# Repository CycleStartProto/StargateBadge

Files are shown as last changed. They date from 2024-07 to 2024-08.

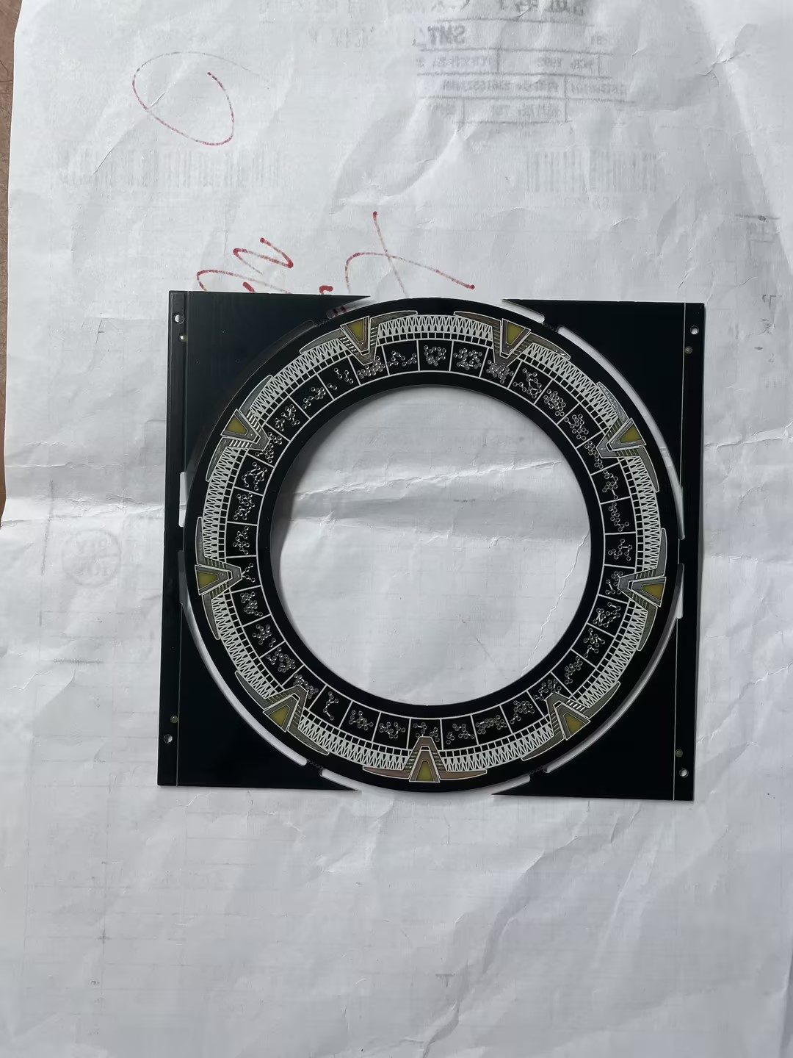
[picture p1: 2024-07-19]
pictures/1.jpg

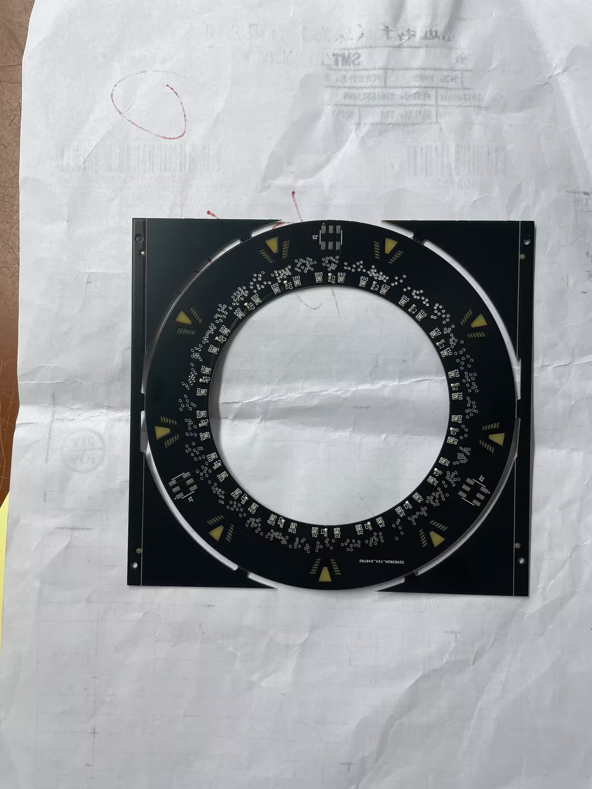
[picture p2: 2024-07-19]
pictures/2.jpg

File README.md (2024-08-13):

# StargateBadge
A fun little limited run badge project


Full repo with 3d files: https://drive.google.com/file/d/1T7bEAc4z4qsCiE_2lE-3noR91gCBkVOr/view?usp=drive_link

# Known Issues
- 3d print gets really close to LEDs and can damage them during assembly, be VERY CAREFUL
  - Doing a light debur with a knife on the edges of the 3d print helps aleviate this issue
- Once a single LED is damaged it can cause large sections of the gate to stop working
  - Only fix is to rework the damaged LED.

# Mechanical Details
- Main structure is provided by the 3d printed core and the 2 circuit boards sandwitched together. 
- 3 pieces of 2x3 pin header hold the whole stack together through friction
- The infinity mirror is made from a 2.5mm thich fully silvered mirror, a piece of 2mm acrylic, and a 1mm 40% semi silvered mirror
- The infinity mirror stack is held in place with another 3d printed spacer to keep it in place and together

# Electrical Details
- 2000mAh Lipo Battery with TP4056 charge controller (set for 600mA charge rate) and power sharing circuit.
- Battery voltage measurement through 750k resistor (to prevent phantom-drain when powerd off) and op-amp buffer to microcontroller ADC
- MT3608 5V Boost converter circuit to ensure consistent LED Supply Voltage
- RP2040 Microcontroller with 128Mbit flash chip
- LIS3DHTR Accelerometer
- 74LVC4245APW Level shifter to ensure reliable addressable LED operation
- a total of 126 XL-1010RGBC-WS2812B 1mmx1mm addressable LEDs

# Firmware Details
- Adafruit Circuitpython and accompanying libraries for accelerometer and addressable LED's
- Custom animation parser for reading animations stored in plain-text format on flash (see command structure.txt in firmware folder for more info)
- Main settings stored as .txt file on flash (see BoardSettings.txt)
- Seperate USB-Serial endpoint exposed to accept animation commands
  - Same command structure as animation file
  - Will execute along side or on top of commanded animation file
  - Can be used to stream animations from seperate pc/controller
- 4 tactile buttons
  - UK1 (GP10) Dial outgoing wormhole
  - UK2 (GP11) Display battery voltage (will interrupt dial animations)
  - UK3 (GP12) Mode Select (switches between dial mode, accelerometer display mode, and rainbow mode)
  - UK4 (GP13) Incoming wormhole
- In random dial mode (default mode) gate will randomly dial an incoming or outgoing sequence based on randomization settings in BoardSettings.txt

# Animation Generators
- run on PC to quickly generate animation files to be loaded onto board
- Animation generators require python 3.9 or newer installed
- Run GenerateDialSeq.py to generate incoming, outgoing, idle, and close animation files
  - tweaking this generator is the easiset way to change relative brightnesses, chevron and glyph color, etc
- Run RainbowGen.py to generate rainbow animation
- Stargate mounts as USB flash drive, copy coresponding .anim files to root of circuitpython drive to load.

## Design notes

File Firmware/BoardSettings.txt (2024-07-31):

------------------------------------
Animation files
------------------------------------

name of animation to load on startup
Startup File: startup.anim;

name of outgoing wormhole animation
Outgoing Animation: outgoing.anim;

name of incoming wormhole animation
Incoming Animation: incoming.anim;

name of gate active idle animation
Idle Animation: idle.anim;

name of gate shutdown animation
Shutdown Animation: close.anim;

name of alternate animation (turned on by uk3)
Alternate Animation: rainbow.anim;

------------------------------------
Stargate Dialing Settings
------------------------------------

Gate Auto Close Time (set to 0 to disable):
Auto Close Time: 42.0; (s)

Random Dial Check interval (how frequently it rolls the dice):
Random Dial Check: 15.0; (s)

Random Dial Chance of dialing (out of 100):
Random Dial Chance: 15;

Random Dialing Option (1 = incoming only, 2 = outgoing only, 3 = 50/50 mix both)
Random Dial Mode: 3;

-----------------------------------
LED/animation settings
-----------------------------------

set default brightness (can be overridden by external commands)
Default Brightness: 0.5; (floating Point, 0.0-1.0)

number of pixel in each strand
Strand Length: 36;

Default Animation Frame Delay:
Default Frame Delay: 15; (ms)

----------------------------------
Battery Settings
----------------------------------

Battery Low Voltage Shut Down Threshold (2.5V min):
Low Voltage Thresh: 2.8; (V)

Battery Voltage display mode (1 = glyphs, 2 = wormhole, 3 = both):
Bat Display Mode: 3;

ADC Battery Voltage measurement cal values

ADC Scale: 0.0000760646106;
ADC Offset: 0.0;

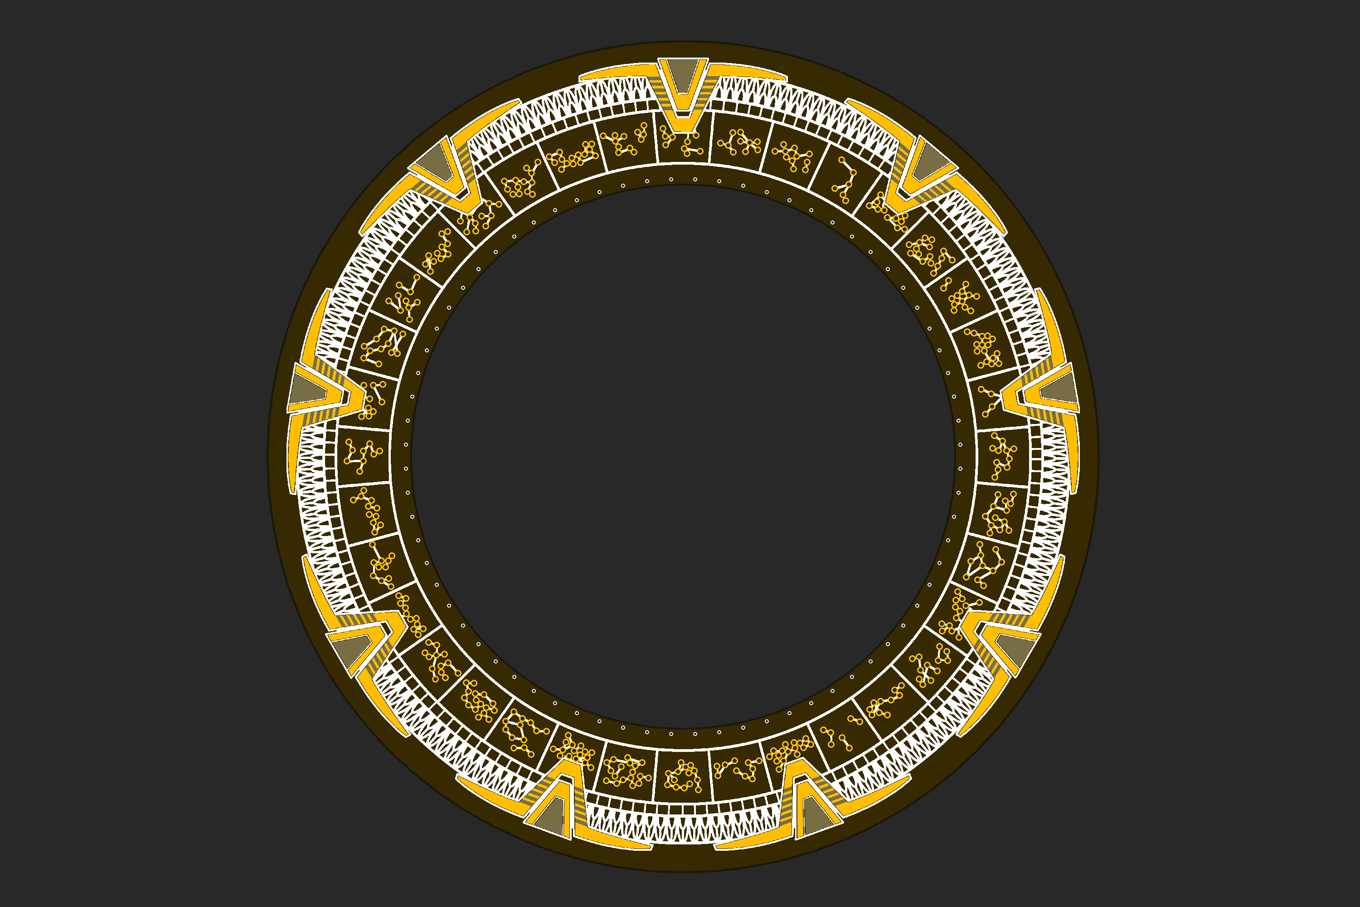
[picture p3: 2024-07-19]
hardware/circuit boards/front board/pdf/Front Board v34 bottom.png

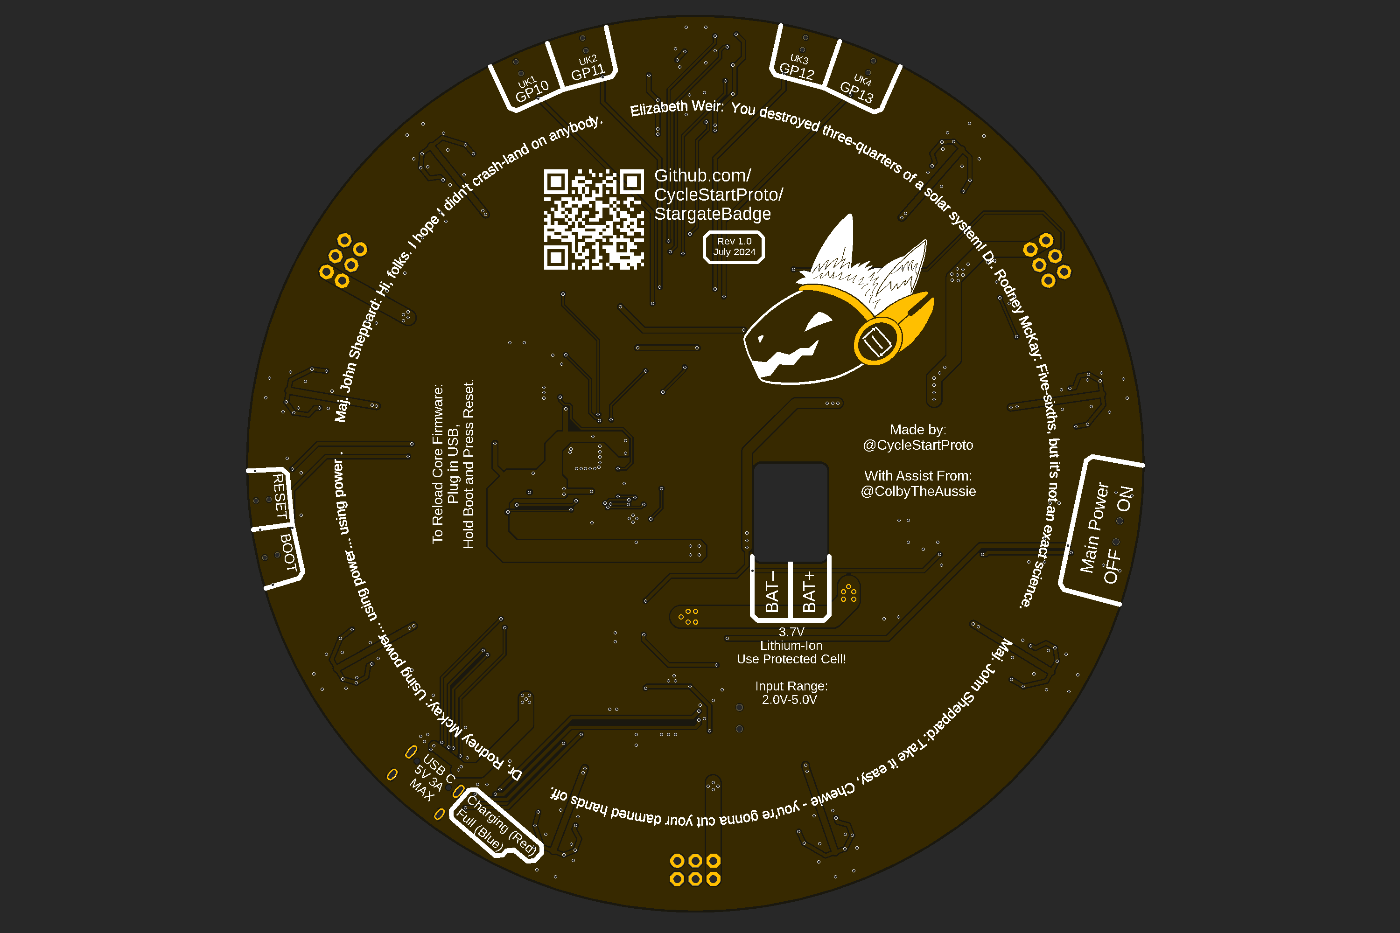
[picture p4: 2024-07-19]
hardware/circuit boards/rear board/pdf/Rear Board v74 bottom.png

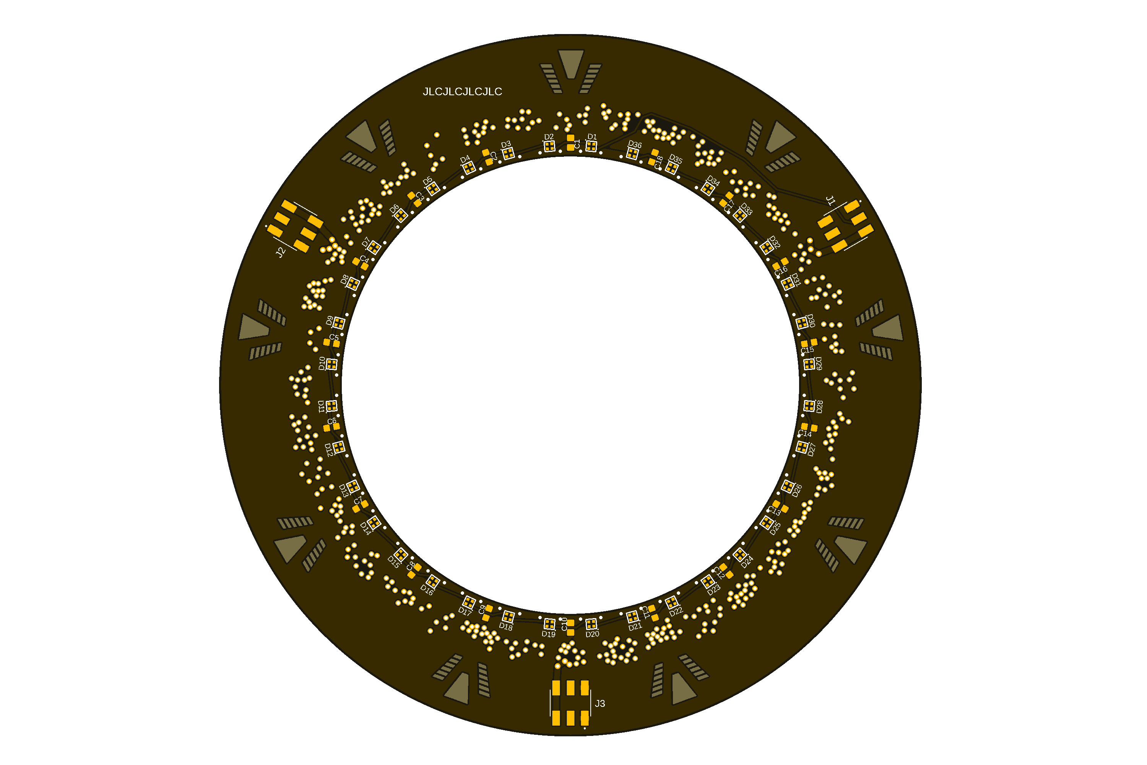
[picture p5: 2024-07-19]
hardware/circuit boards/front board/pdf/Front Board v34 top.png

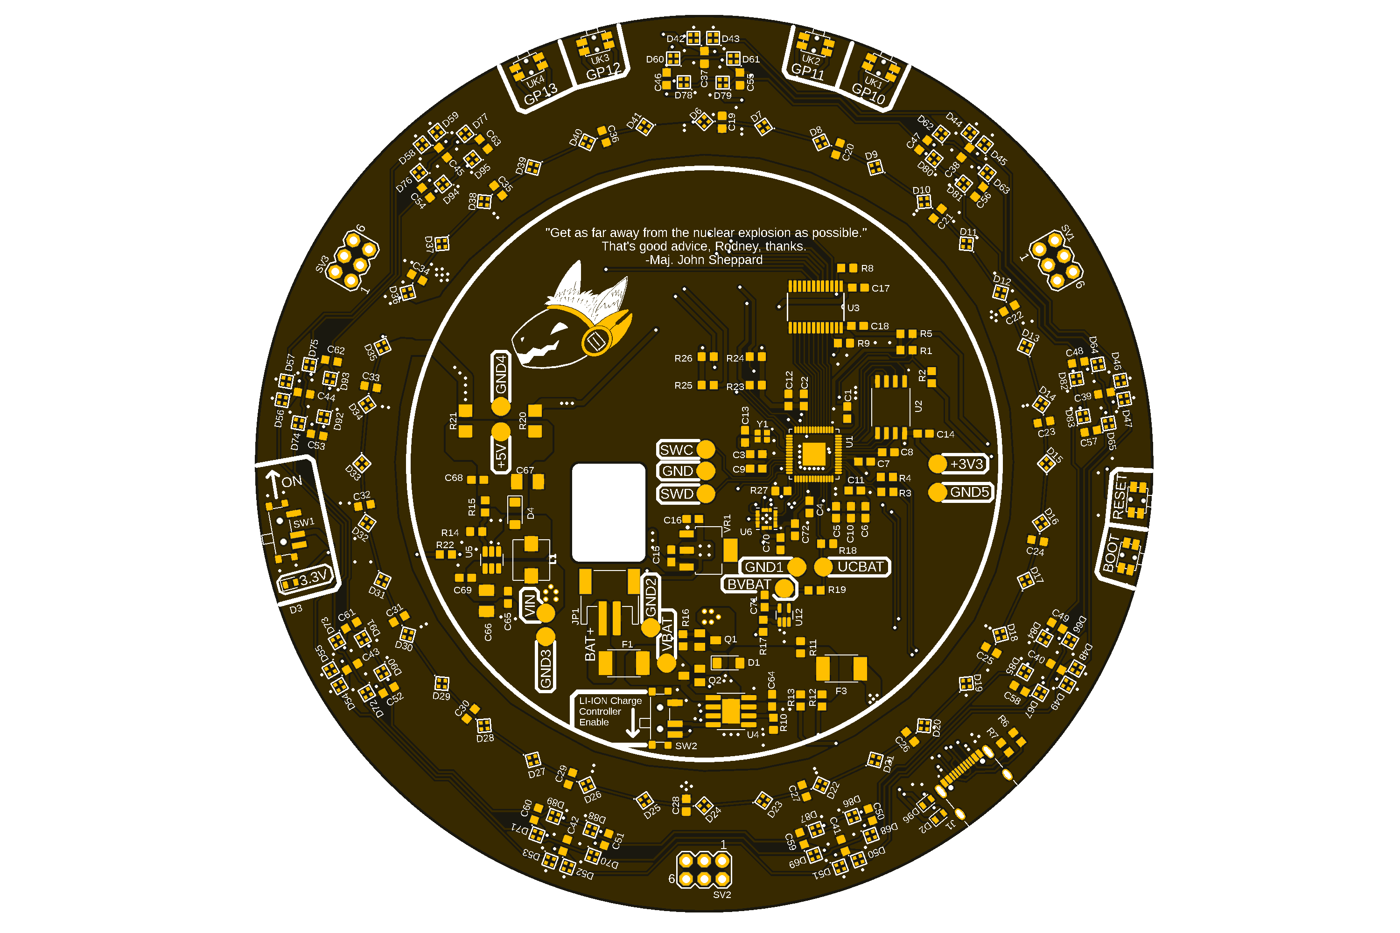
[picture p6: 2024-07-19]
hardware/circuit boards/rear board/pdf/Rear Board v74 top.png

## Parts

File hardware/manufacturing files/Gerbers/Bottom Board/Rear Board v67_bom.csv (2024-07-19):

Comment | Designator | Footprint | LCSC Part #
 | BOOT | SKSCLDE010 | C115362
 | RESET | SKSCLDE010 | C115362
 | UK1 | SKSCLDE010 | C115362
 | UK2 | SKSCLDE010 | C115362
 | UK3 | SKSCLDE010 | C115362
 | UK4 | SKSCLDE010 | C115362
0 | R20 R21 | R1206 | C304418
1K | R2 R12 R13 R14 | R0603 | C110776
1u | C10 C11 C65 C68 | C0603 | C59302
2k | R10 R22 | R0603 | C2758291
4u7 | L1 | INDUCTOR_5X5MM | C177246
5.1k | R6 R7 R19 | R0603 | C105580
7k5 | R15 | R0603 | C374583
10k | R1 R5 R8 R9 R11 R16 R18 R23 R24 R25 R26 R27 | R0603 | C115324
10u | C12 C15 C16 C72 | C0603 | C19702
12MHz | Y1 | WE-SPXO_IQXO-540 | C2901608
22u | C66 C67 | C1206K | C5137635
27R | R3 R4 | R0603 | C2907021
74LVC4245APW | U3 | SOP65P640X110-24N | C7859
100n | C1 C2 C3 C4 C5 C6 C7 C8 C9 C13 C14 C17 C18 C64 C69 C70 C71 | C0603 | C1591
100n | C19 C20 C21 C22 C23 C24 C25 C26 C27 C28 C29 C30 C31 C32 C33 C34 C35 C36 C37 C38 C39 C40 C41 C42 C43 C44 C45 C46 C47 C48 C49 C50 C51 C52 C53 C54 C55 C56 C57 C58 C59 C60 C61 C62 C63 | C0603K | C1591
470k | R17 | R0603 | C224602
1812L010 | F1 F3 | FUSC4532X125 | C127824
DMP1045U | Q1 Q2 | SOT23 | C22366440
DSK34 | D1 D4 | SODFL3718X115 | C3015221
JSTPH2 | JP1 | JSTPH2 | C295747
LED_BLUE | D2 | LEDC1608X35N_FLAT-B | C965807
LED_RED | D96 | LEDC1608X35N_FLAT-B | C965799
LED_WHITE | D3 | LEDC1608X35N_FLAT-B | C2290
LIS3DHTR | U6 | XDCR_LIS3DHTR | C15134
LM321LVIDCKR | U12 | SOT65P210X110-5N | C484727
MSK-12C02_SMD_SPDT_SWITCH | SW1 SW2 | MSK-12C02 | C431540
MT3608 | U5 | SOT95P280X145-6N | C84817
NCP1117ST33T3G | VR1 | SOT230P700X170-4 | C347222
RP2040 | U1 | QFN40P700X700X90-57N | C2040
TP4056 | U4 | SOP127P600X175-9N | C725790
TYPE-C-31-M-12 | J1 | HRO_TYPE-C-31-M-12 | C165948
W25Q128JVSIQ | U2 | SOIC127P790X216-8N | C97521
WS2812B | D6 D7 D8 D9 D10 D11 D12 D13 D14 D15 D16 D17 D18 D19 D20 D21 D22 D23 D24 D25 D26 D27 D28 D29 D30 D31 D32 D33 D34 D35 D36 D37 D38 D39 D40 D41 D42 D43 D44 D45 D46 D47 D48 D49 D50 D51 D52 D53 D54 D55 D56 D57 D58 D59 D60 D61 D62 D63 D64 D65 D66 D67 D68 D69 D70 D71 D72 D73 D74 D75 D76 D77 D78 D79 D80 D81 D82 D83 D84 D85 D86 D87 D88 D89 D90 D91 D92 D93 D94 D95 | 1010 | C5349953

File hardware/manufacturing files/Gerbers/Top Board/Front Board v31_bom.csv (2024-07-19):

Comment | Designator | Footprint | LCSC Part #
100n | C1 C2 C3 C4 C5 C6 C7 C8 C9 C10 C11 C12 C13 C14 C15 C16 C17 C18 | C0603K | C1591
WS2812B | D1 D2 D3 D4 D5 D6 D7 D8 D9 D10 D11 D12 D13 D14 D15 D16 D17 D18 D19 D20 D21 D22 D23 D24 D25 D26 D27 D28 D29 D30 D31 D32 D33 D34 D35 D36 | 1010 | C5349953

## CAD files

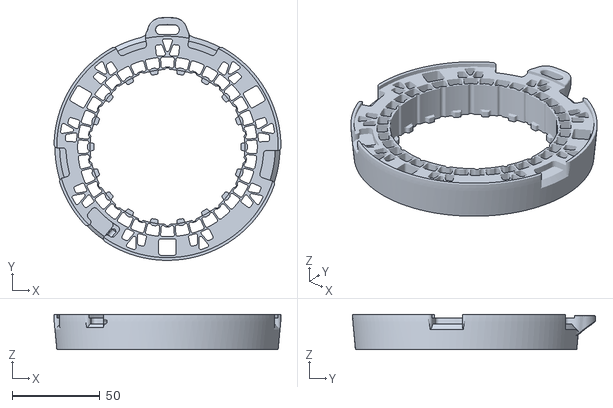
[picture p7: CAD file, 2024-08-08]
hardware/mechanical/Light Dam v22.stl
129.7 x 138.7 x 20.1

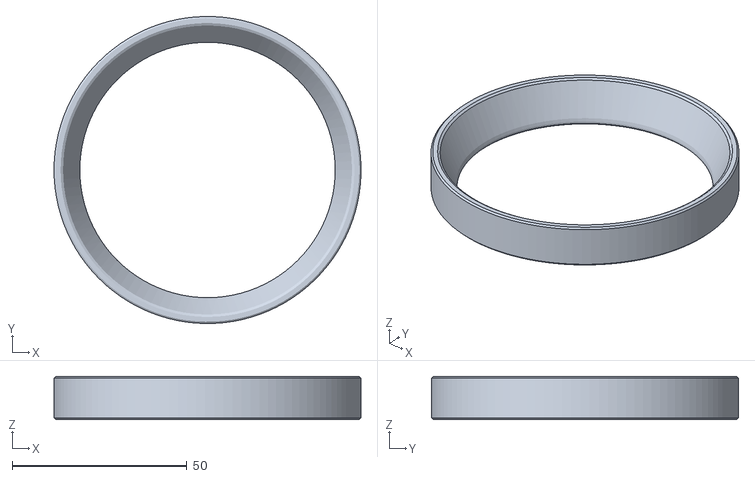
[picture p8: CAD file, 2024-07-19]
hardware/mechanical/spacer ring v6.stl
87.8 x 87.8 x 12.4

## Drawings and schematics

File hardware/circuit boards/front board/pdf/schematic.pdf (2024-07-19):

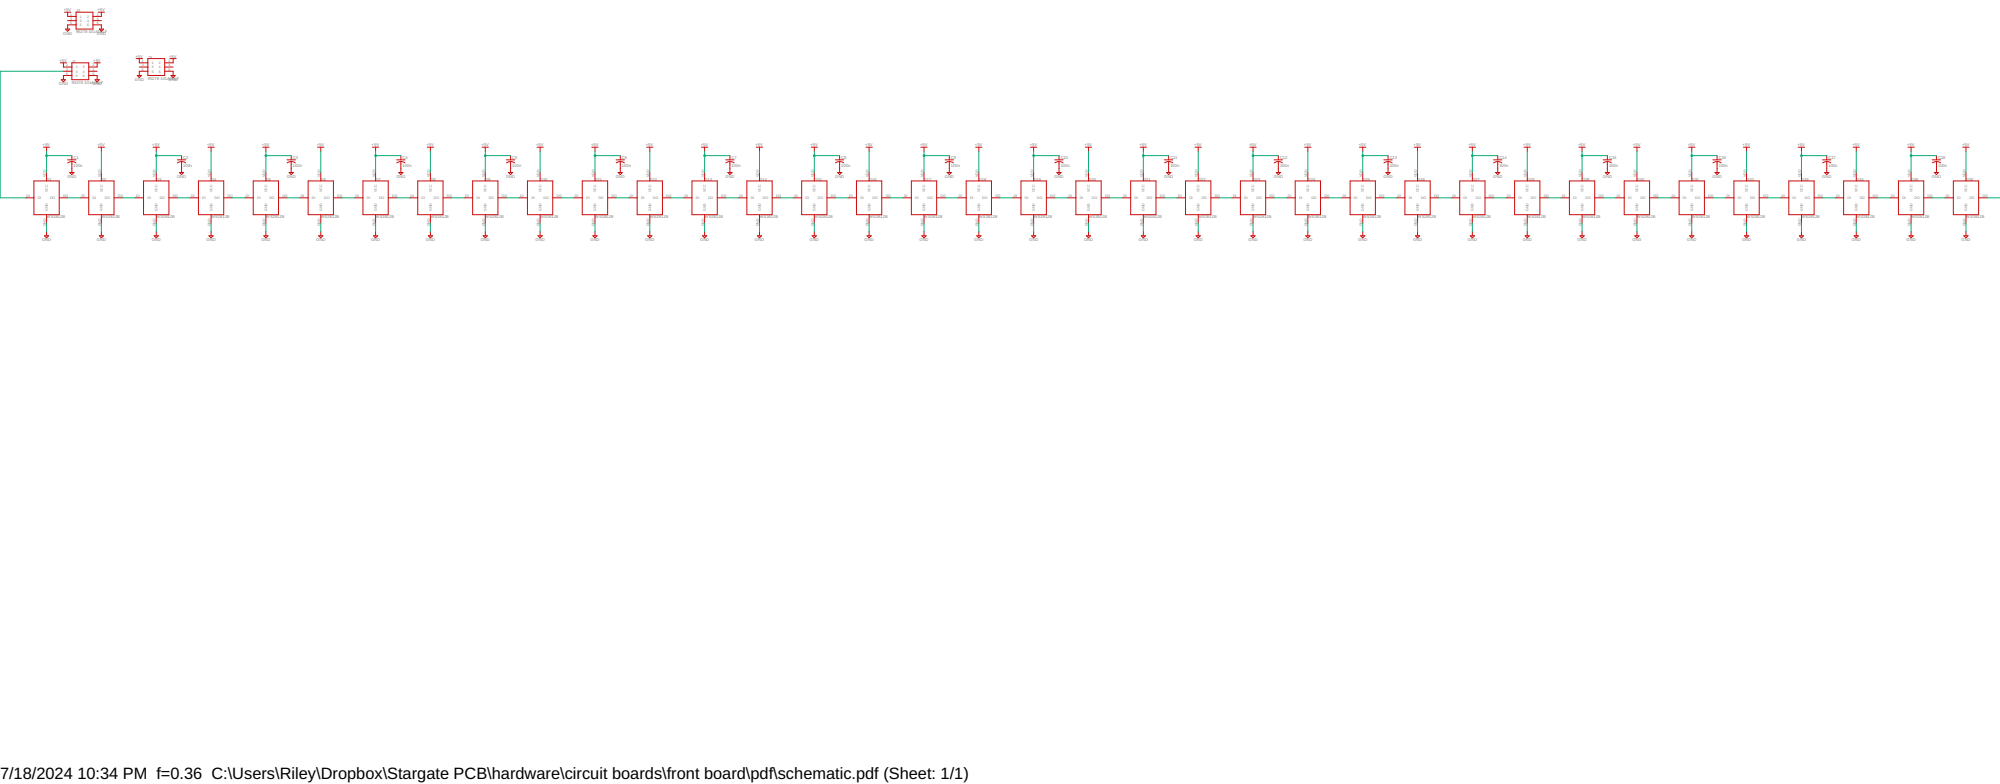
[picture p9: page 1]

7/18/2024 10:34 PM f=0.36 C:\Users\Riley\Dropbox\Stargate PCB\hardware\circuit boards\front board\pdf\schematic.pdf (Sheet: 1/1)

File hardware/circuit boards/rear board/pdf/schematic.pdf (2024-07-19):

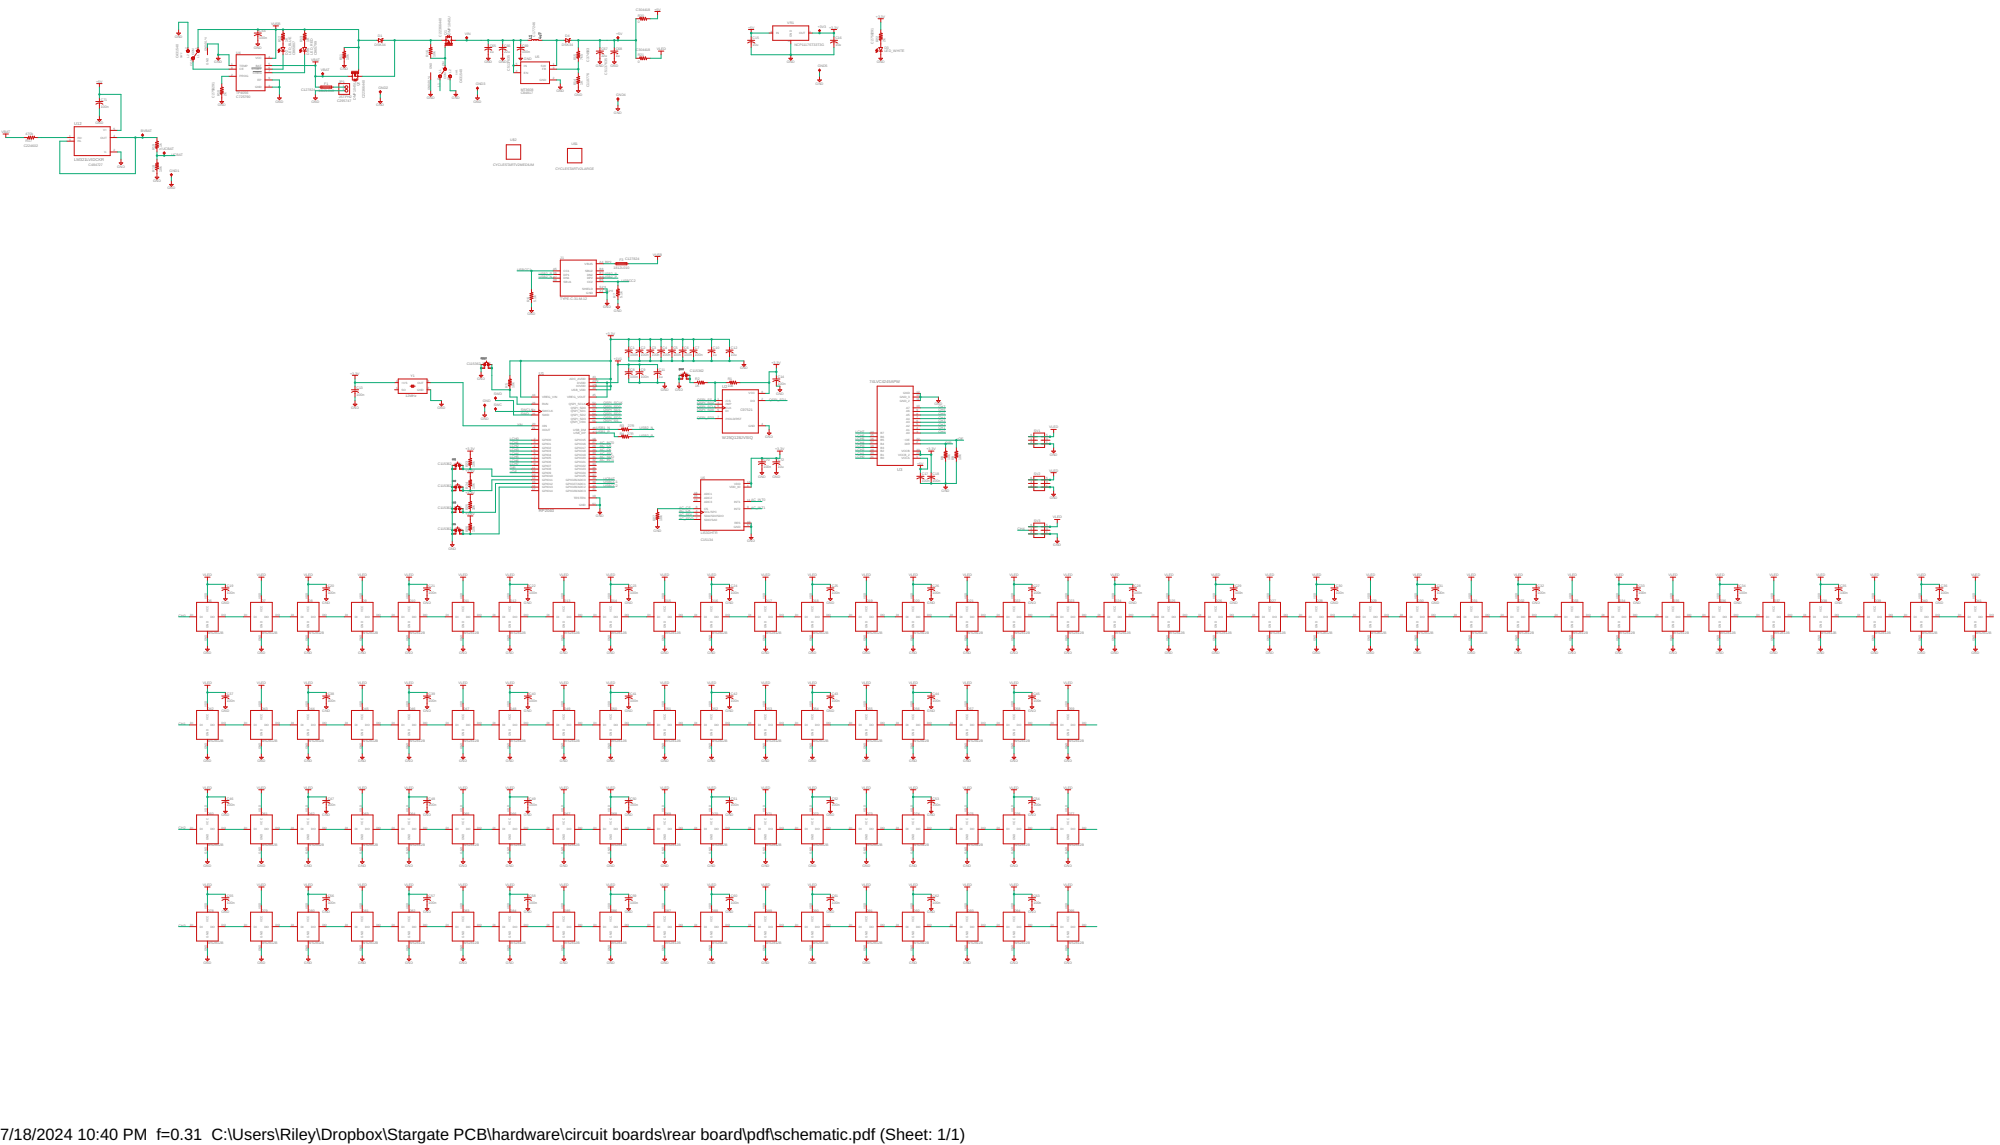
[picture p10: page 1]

7/18/2024 10:40 PM f=0.31 C:\Users\Riley\Dropbox\Stargate PCB\hardware\circuit boards\rear board\pdf\schematic.pdf (Sheet: 1/1)

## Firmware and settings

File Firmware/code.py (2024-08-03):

import board
from digitalio import *
import analogio
import microcontroller
import busio as io
import gc
import os
import math
import supervisor
import adafruit_lis3dh
import rp2pio

import random
import time

from SettingsReader import *
from LedString import LedString
from CommandParser import CommandParser
from serialCommandReader import serialCommandReader
from animReader import animReader

#-----------------------------------------------------------
#Hardware pin setup
#-----------------------------------------------------------

spi = io.SPI(board.GP18, board.GP19, board.GP20)
cs = DigitalInOut(board.GP17)
lis3dh = adafruit_lis3dh.LIS3DH_SPI(spi, cs)

lis3dh.range = adafruit_lis3dh.RANGE_4_G
lis3dh.data_rate = adafruit_lis3dh.DATARATE_25_HZ

LEDOE = DigitalInOut(board.GP9)
LEDOE.direction = Direction.OUTPUT
LEDOE.value = 1

ana = analogio.AnalogIn(board.A0)

bt1 = DigitalInOut(board.GP10)
bt1.direction = Direction.INPUT

bt2 = DigitalInOut(board.GP11)
bt2.direction = Direction.INPUT

bt3 = DigitalInOut(board.GP12)
bt3.direction = Direction.INPUT

bt4 = DigitalInOut(board.GP13)
bt4.direction = Direction.INPUT

#--------------------------------------
# main state machine variable
#--------------------------------------

'''Gate Statemachine variable,
0 = low battery, no display allowed
1 = startup
2 = ready
3 = dialing
4 = connected
5 = closing

20 = show bat voltage
30 = accel ring mode
31 = alternate animation mode'''
gateState = 1

#------------------------------------------------------------
#convienence offsets for setting chevrons and wormholeOffset
#because doing math is hard, so lets make the computer do it
#------------------------------------------------------------

mainChevOffset = 36
outerChevOffset = mainChevOffset+36
innerChevOffset = outerChevOffset+36
wormholeOffset = innerChevOffset+36


def initAll():
    global dispFilePath
    global ser
    global LEDOE
    global sets
    global analog
    global leds
    global CP
    global AR
    global seReader
    microcontroller.cpu.frequency = 133000000
    sets = BoardSettings("BoardSettings.txt")
    leds = LedString(sets)
    CP = CommandParser(leds,sets)
    AR = animReader(leds,sets)
    seReader = serialCommandReader(leds,sets)
    LEDOE.value = 0
    CP.ClearAll()
    CP.frcShow()
    AR.setAnim(sets.StartupFile)
    
def getBatVoltage():
    return (ana.value*sets.ADCCalScale)+sets.ADCCalOffset

def mapVal(x, in_min, in_max, out_min, out_max):
  return (x - in_min) * (out_max - out_min) / (in_max - in_min) + out_min

def batDisp(numleds,startindex):
    redEnd = 6
    yelEnd = 18
    if numleds > 36:
        numleds = 36
    if numleds > redEnd:
        CP.Set(slice(startindex,startindex+redEnd),0xFF0000)
        if numleds > yelEnd:
            CP.Set(slice(startindex+redEnd,startindex+yelEnd),0xFF5000)
            CP.Set(slice(startindex+yelEnd,startindex+numleds),0x00FF00)
        else:
            CP.Set(slice(startindex+redEnd,startindex+numleds),0xFFFF00)
    else:
        CP.Set(slice(startindex,startindex+numleds),0xFF0000)

def main():
    global gateState
    trap = False
    bttrap = False
    lastRandCheck = time.monotonic()
    shutdownTime = 0
    currentTime = time.monotonic()
    while True:
        batV = getBatVoltage()
        currentTime = time.monotonic()
        
        #------------------------------------
        #Low battery state, turn off all LEDs
        #------------------------------------
        if batV < sets.BatLowVoltageThresh:
            CP.Halt()
            CP.ClearAll()
            CP.frcShow()
            gateState = 0
            
        #------------------------------------------------------------------------------
        #Button State trap, prevents button presses from racing through possible states
        #------------------------------------------------------------------------------
        
        if bt2.value and bt1.value and bt3.value and bt4.value:
            bttrap = False
        
        #----------------------------------------------------------
        #Button press catch for Alternate mode display (state 30)
        #----------------------------------------------------------
        if not bt3.value and not bttrap and gateState < 30:
            bttrap = True
            CP.Halt()
            CP.ClearAll()
            CP.setDefaultBrightness()
            gateState = 30
            
        #--------------------------------
        #Accelerometer display main logic
        #--------------------------------
        
        elif gateState == 30:
            ringColor = 0x505050
            wormColor = 0x00000B
            ax, ay, az = lis3dh.acceleration
            mag = math.sqrt(math.pow(ax,2)+math.pow(ay,2))
            theta = math.degrees(math.atan2(ax,ay))
            CP.ClearAll()
            if mag < 0.3:
                CP.Set(slice(mainChevOffset,mainChevOffset+18,6),0x880600)
                CP.Set(slice(innerChevOffset,innerChevOffset+18,6),0x880600)
                CP.Set(slice(outerChevOffset,outerChevOffset+18,6),0x880600)
                CP.Set(slice(mainChevOffset+1,mainChevOffset+18,6),0x880600)
                CP.Set(slice(innerChevOffset+1,innerChevOffset+18,6),0x880600)
                CP.Set(slice(outerChevOffset+1,outerChevOffset+18,6),0x880600)
            else:
                center = (190.0+theta)%360
                num = abs(205-((mag/9.8)*200.0))
                left = int((center - (num/2))/10.0)
                right = int((center + (num/2))/10.0)
                if right > 36:
                    CP.Set(slice(0,right-36),ringColor)
                    CP.Set(slice(wormholeOffset,wormholeOffset+(right-36)),wormColor)
                    right = 36
                if left < 0:
                    CP.Set(slice(36+left,36),ringColor)
                    CP.Set(slice(wormholeOffset+(36+left),wormholeOffset+36),wormColor)
                    left = 0
                CP.Set(slice(left,right),ringColor)
                CP.Set(slice(wormholeOffset+left,wormholeOffset+right),wormColor)
            CP.frcShow()
            if not bt3.value and not bttrap:
                bttrap = True
                trap = False
                CP.Halt()
                CP.ClearAll()
                CP.frcShow()
                gateState = 31
                
        #--------------------------------------------------------
        #Alternate Animation mode
        #--------------------------------------------------------
        
        elif gateState == 31:
            if not trap:
                AR.setAnim(sets.AltAnim)
                trap = True
            if AR.animFinished:
                trap = False
            if not bt3.value and not bttrap:
                bttrap = True
                trap = False
                CP.Halt()
                CP.ClearAll()
                CP.frcShow()
                gateState = 2
        
        #----------------------------------------------------------------
        #Button Press State Catch for Battery capacity display (state 20)
        #----------------------------------------------------------------
        
        elif not bt2.value and not bttrap and gateState != 20:
            bttrap = True
            gateState = 20
            CP.Halt()
            CP.ClearAll()
            CP.Brightness(0.3)
            
        #------------------------------------
        #Battery capacity display main logic
        #------------------------------------
        
        elif gateState == 20:
            CP.ClearAll()
            numleds = int(mapVal(batV,sets.BatLowVoltageThresh+0.4,4.19,0,36))
            if sets.BatDispMode == 1 or sets.BatDispMode == 3:
                batDisp(numleds,0)
            if sets.BatDispMode == 2 or sets.BatDispMode == 3:
                batDisp(numleds,wormholeOffset)
            CP.frcShow()
            if not bt2.value and not bttrap:
                bttrap = True
                trap = False
                CP.Halt()
                CP.ClearAll()
                CP.frcShow()
                gateState = 2
                
        #--------------------------------------------------------------------
        #Gate Power On Startup state (waits until startup animation finishes)
        #--------------------------------------------------------------------
            
        elif gateState == 1:
            if AR.animFinished:
                gateState = 2
        
        #-------------------------------------------------
        #Gate dark but ready, wait for starting conditions
        #-------------------------------------------------
        
        elif gateState == 2:
            if currentTime > (lastRandCheck+sets.RandomDialCheckInterval) and sets.RandomDialChance != 0:
                lastRandCheck = currentTime
                randomInt = random.randint(0,100)
                if randomInt < sets.RandomDialChance:
                    if sets.RandomDialMode == 3:
                        if randomInt%2 == 0:
                            gateState = 3
                        else:
                            gateState = 6
                    elif sets.RandomDialMode == 2:
                        gateState = 3
                    else:
                        gateState = 6
            if not bt1.value and not bttrap:
                bttrap = True
                gateState = 3
            elif not bt4.value and not bttrap:
                bttrap = True
                gateState = 6
                
        #----------------------
        #Dial outgoing wormhole
        #----------------------
        elif gateState == 3:
            if not trap:
                AR.setAnim(sets.OutgoingAnim)
                trap = True
            if AR.animFinished:
                trap = False
                if sets.AutoCloseTime != 0:
                    shutdownTime = currentTime + sets.AutoCloseTime
                gateState = 4
        #------------------------
        #Dial Incoming wormhole
        #------------------------
        elif gateState == 6:
            if not trap:
                AR.setAnim(sets.IncomingAnim)
                trap = True
            if AR.animFinished:
                trap = False
                if sets.AutoCloseTime != 0:
                    shutdownTime = currentTime + sets.AutoCloseTime
                gateState = 4
                
        #--------------------------------------
        #Active wormhole idle animation (loops)
        #--------------------------------------
                
        elif gateState == 4:
            if not trap:
                AR.setAnim(sets.IdleAnim)
                trap = True
            if AR.animFinished:
                trap = False
            if currentTime > shutdownTime and sets.AutoCloseTime != 0:
                trap = False
                gateState = 5
            if not bt1.value and not bttrap:
                bttrap = True
                trap = False
                gateState = 5
            if not bt4.value and not bttrap:
                bttrap = True
                trap = False
                gateState = 5
        #----------------------------------
        #Gate Shutdown  animation
        #----------------------------------
        
        elif gateState == 5:
            if not trap:
                AR.setAnim(sets.CloseAnim)
                trap = True
            if AR.animFinished:
                trap = False
                lastRandCheck = currentTime
                gateState = 2
                
        #-------------------------------------
        #cyclic calls to update all the things
        #-------------------------------------
        AR.cyclicCall()
        seReader.cyclicCall()
        time.sleep(0.0001)





if __name__ == '__main__':
    initAll()
    main()

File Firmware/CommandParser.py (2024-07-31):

from LedString import LedString
import random
import time

class CommandParser:
    #List of valid commands
    CommandList = [
    "#",
    "CLR",
    "SET",
    "DLY",
    "DEFDLY",
    "RANDLY",
    "BRT",
    "DEFBRT",
    "LOD",
    "HALT",
    "SHOW"]

    #Last (and current) known good command (index of above array)
    Command = -1

    #Last (and current) known good array index
    Index = -1

    #last (and current) array slice
    lastSlice = slice(None,None,None)

    #Last (and current) known good color value
    Color = 0x000000

    #Led String Control Object
    leds = None

    #local frame delay
    frmDelay = 0

    #local brightness
    localBright = 0

    #call pixels.show() when a delay is called
    showOnDelay = True

    #in waiting mode
    waitmode = False

    #monotonic time to run next command
    nextCommandAllowed = 0
    
    #Command Parser Requests a HALT
    haltRequested = False
    
    #command Parser Requests a file load
    loadRequested = False
    
    #load request File name
    loadReqFile = ""

    def __init__(self,ledStringIn,settings):
        self.leds = ledStringIn
        self.sets = settings
        self.frmDelay = self.sets.DefaultFrameDelay
        self.localBright = self.sets.DefaultBrightness

    def isReady(self):
        if time.monotonic()>=self.nextCommandAllowed or not self.waitmode:
            self.waitmode = False
            return True
        else:
            return False

    def parse(self, instr):
        if self.Command == 2:
            return self.parseSet(instr)
        elif self.Command == 1:
            if instr[0] == "I":
                self.lastSlice = self.make_slice(instr[1:len(str)])
                self.Clear(self.lastSlice)
                return 1
            else:
                return self.parseFullCommand(instr)
        else:
            return self.parseFullCommand(instr)


    def parseSet(self,instr):
        if instr[0] == "I":
            strAr = instr.split(" ")
            self.lastSlice = self.make_slice(strAr[0][1:len(strAr[0])])
            self.Index = self.lastSlice.stop-1
            if len(strAr) == 1:
                self.Set(self.lastSlice,self.Color)
                return 1
            elif len(strAr) == 2:
                self.Color = int(strAr[1][1:len(strAr[1])],16)
                self.Set(self.lastSlice,self.Color)
                return 1
            else:
                raise Exception("Failed To Parse Command, Incorrect Number of Parameters")
        elif instr[0] == "C" and instr[1] != "L":
            self.Color = int(instr[1:len(instr)],16)
            self.Index = self.Index+1
            self.singleSet(self.Index,self.Color)
            return 1
        else:
            return self.parseFullCommand(instr)

    def parseFullCommand(self,instr):
        if(instr[0] != "#"):
            strAr = instr.split(" ")
            try:
                self.Command = self.CommandList.index(strAr[0])
            except:
                print("\nInvalid Command, Check Formating, spelling, and capitalization\n")
                return -1
            else:
                if self.Command == 2:
                    if len(strAr) == 3:
                        return self.parseSet(strAr[1]+" "+strAr[2])
                    elif len(strAr) == 2:
                        return self.parseSet(strAr[1])
                    else:
                        raise Exception("Failed To Parse Command, Incorrect Number of Parameters")
                elif self.Command == 1:
                    if len(strAr) == 2:
                        self.lastSlice = self.make_slice(strAr[1][1:len(strAr[1])])
                        self.Clear(self.lastSlice)
                        return 1
                    elif len(strAr) == 1:
                        self.ClearAll()
                        return 1
                    else:
                        raise Exception("Failed To Parse Command, Incorrect Number of Parameters")
                elif self.Command == 3:
                    if len(strAr) == 1:
                        self.Delay()
                        return 1
                    elif len(strAr) == 2:
                        self.DelayTime(int(strAr[1][1:len(strAr[1])]))
                        return 1
                    else:
                        raise Exception("Failed To Parse Command, Incorrect Number of Parameters")
                elif self.Command == 4:
                    if len(strAr) == 2:
                        self.setDefDelay(int(strAr[1][1:len(strAr[1])]))
                        return 1
                    else:
                        raise Exception("Failed To Parse Command, Incorrect Number of Parameters")
                elif self.Command == 5:
                    if len(strAr) == 3:
                        self.RandomDelay(int(strAr[1][1:len(strAr[1])]),int(strAr[2][1:len(strAr[2])]))
                        return 1
                    else:
                        raise Exception("Failed To Parse Command, Incorrect Number of Parameters")
                elif self.Command == 6:
                    if len(strAr) == 2:
                        self.Brightness(float(strAr[1][1:len(strAr[1])]))
                        return 1
                    else:
                        raise Exception("Failed To Parse Command, Incorrect Number of Parameters")
                elif self.Command == 7:
                    if len(strAr) == 1:
                        self.setDefaultBrightness()
                        return 1
                    else:
                        raise Exception("Failed To Parse Command, Incorrect Number of Parameters")
                elif self.Command == 8:
                    if len(strAr) == 2:
                        self.LoadAnim(strAr[1][0:len(strAr[1])])
                        return 1
                    else:
                        raise Exception("Failed To Parse Command, Incorrect Number of Parameters")
                elif self.Command == 9:
                    if len(strAr) == 1:
                        self.Halt()
                        return 1
                    else:
                        raise Exception("Failed To Parse Command, Incorrect Number of Parameters")
                elif self.Command == 10:
                    if len(strAr) == 1:
                        self.frcShow()
                        return 1
                    else:
                        raise Exception("Failed To Parse Command, Incorrect Number of Parameters")
                else:
                    raise Exception("\nInvalid Command\n")


    def make_slice(self,expr):
        def to_piece(s):
            return s and int(s)
        pieces = list(map(to_piece, expr.split(':')))
        if len(pieces) == 1:
            return slice(pieces[0], pieces[0] + 1)
        else:
            return slice(*pieces)

    def ClearAll(self):
        self.leds.pixels.fill(0)
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

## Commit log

2024-07-19 initial upload
    [Front Board v31_bom.csv, Front Board v31_bom.xls, Front_Board_v6.sch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]
2024-07-21 removed debug prints from serial parser
2024-07-22 Added battery voltage display and accelerometer visualization mode
2024-07-23 updated battery display to be more human readable, put the animation file names for the variious states into the settings file for convienvence, added some input sanitization to the settings reader, 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
2024-07-31 added scan delay to improve stability
    [code.py]
2024-08-08 Fixed 3d print interference
    [Light Dam v21.stl, Light Dam v22.stl]
